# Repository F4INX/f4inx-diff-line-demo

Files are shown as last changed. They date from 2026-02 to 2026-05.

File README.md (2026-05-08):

# Differential pairs experiments

## Introduction and context

A few years ago, following a post about discontinuities of reference planes planes, I stated that differential pairs were popular precisely because they are more tolerant to reference planes discontinuities than single-ended ones, typically due to the following causes:

* Change of reference ground plane in multilayer boards.

* Slot between voltage domains where a power plane is use as a reference plane.

* Slots in the copper pour due to traces inside for 2 layers PCBs using copper fills as ground planes.

Indeed, there is no fundamental physical reason for differential lines alone, without discontinuities, to have better performance than grounded single-ended lines.

After this discussion, I made preliminary experiments to confirm some of my ideas on the subjects, but I did not have time yet to make a more comprehensive test.

After a recent discussion a few weeks ago, I had an idea to perform quick and low cost experiments on the subjects which is presented now.

## Precisions on the statement

After some discussions telling that differential pairs are not totally immune to ground plane issues, some points must be precised:

* Even when differential pairs have a greater resistance to ground plane defects from a functional point of view, the parasitic common mode is likely to cause EMC emissivity issues.

* Some performance degradation is to be expected indeed.

* But the remaining performance is more likely to stay sufficient for functional operation than for single-ended lines.

* The slots are assumed thin, which corresponds to the most common cases.

* For a thin slot, the dominant effect is not the short section with increased impedance, precisely because it is short, but the current redistribution effect explained later.

## Household experiments

### Materials

The only needed material is a low cost HDMI cable. Lowest cost as possible since it will be rather botched. The ticket showing the rather low cost can be seen. The cat is optional, although much welcome.

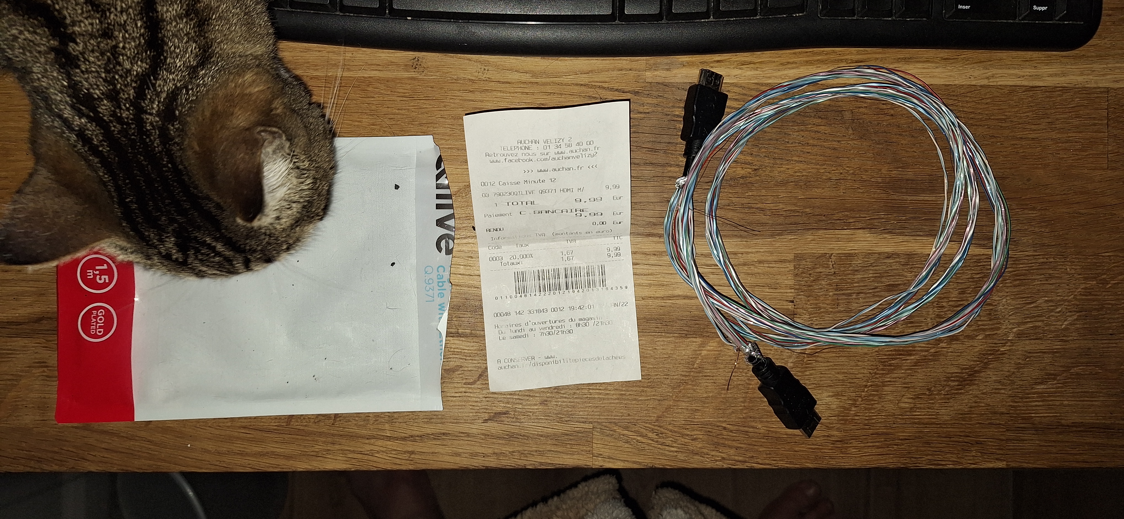
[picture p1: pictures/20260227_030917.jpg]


### Strongly coupled differential pair

First, as a reference, the HDMI pair is measured without its shields, both the outer shield and the inner shields of the pairs.

The small ground wire following the shields was left, even if disconnected. **It can be ignored for understanding of what follows**.

A picture was properly transmitted and displayed using this cable.

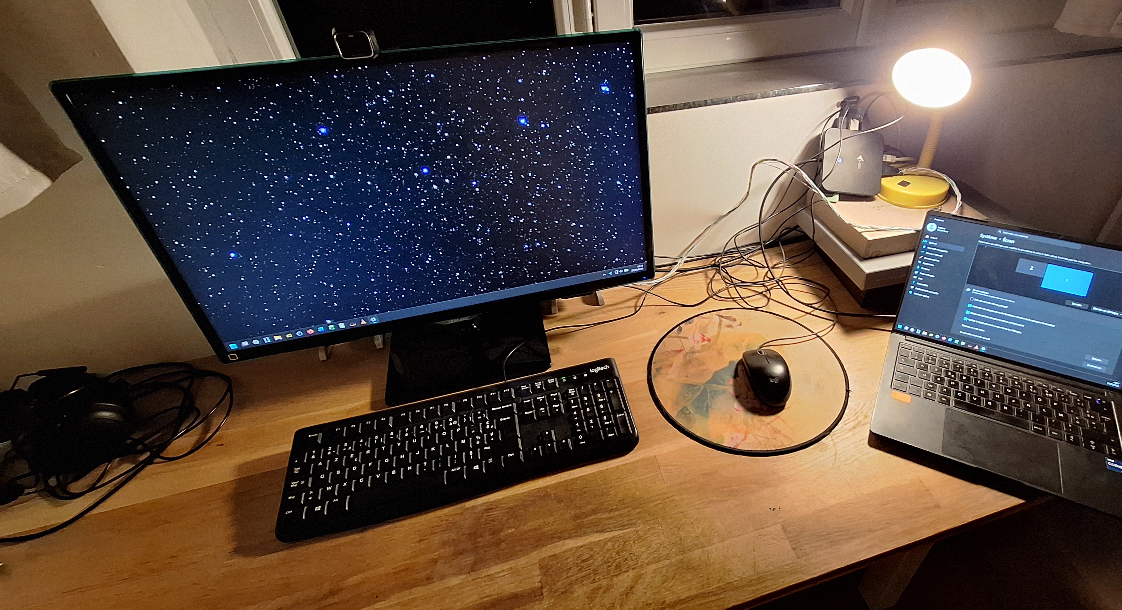
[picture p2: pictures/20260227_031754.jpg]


**Conclusion:** strongly coupled differential pairs don't need a ground "plane" for proper functional operation. ("Plane" in quotes because not plane for a cable, but has the same function.) Shielding is mainly for EMC issues. The question of DC connection to have proper common-mode DC voltage is left aside, but this point is rarely an issue in practice. This case is very common in cables, but in PCBs, the coupling is rarely sufficient to be able to work without a ground plane.

### Very loosely coupled differential pair, with or withound ground

The situation is very different for a loosely differential pair: the characteristic impedance of such lines without a ground plane is too high to ensure a proper operation. The ground plane allows to maintain a correct impedance despite the distance.

As shown below, loosely coupled differential pair without a ground plane have a too high impedance to ensure a proper operation:

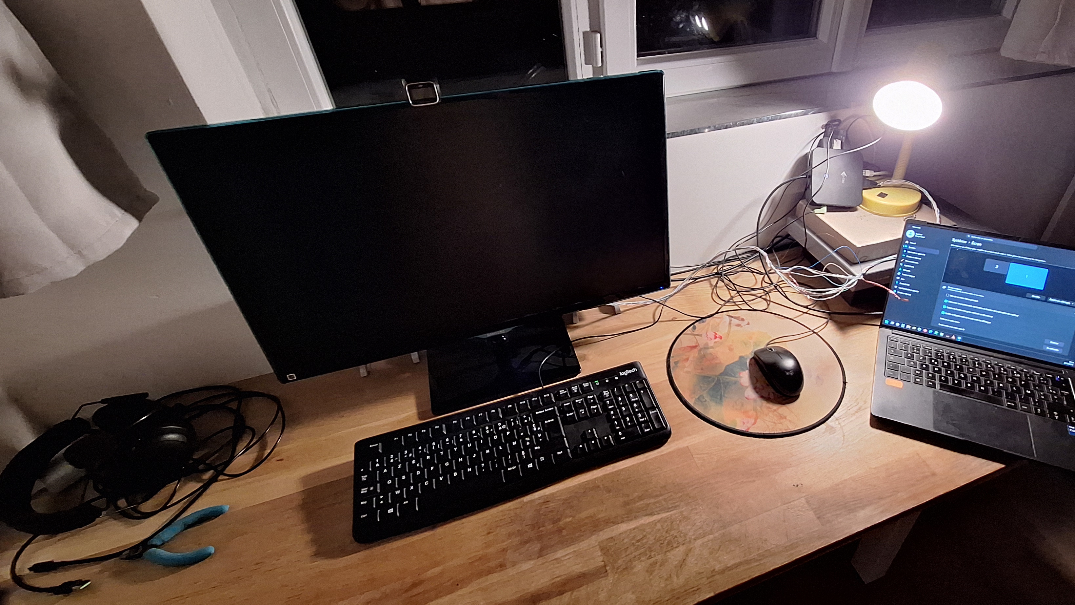
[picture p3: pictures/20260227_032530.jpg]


Adding a ground plane lowers this impedance and allows the differential pair to work again:

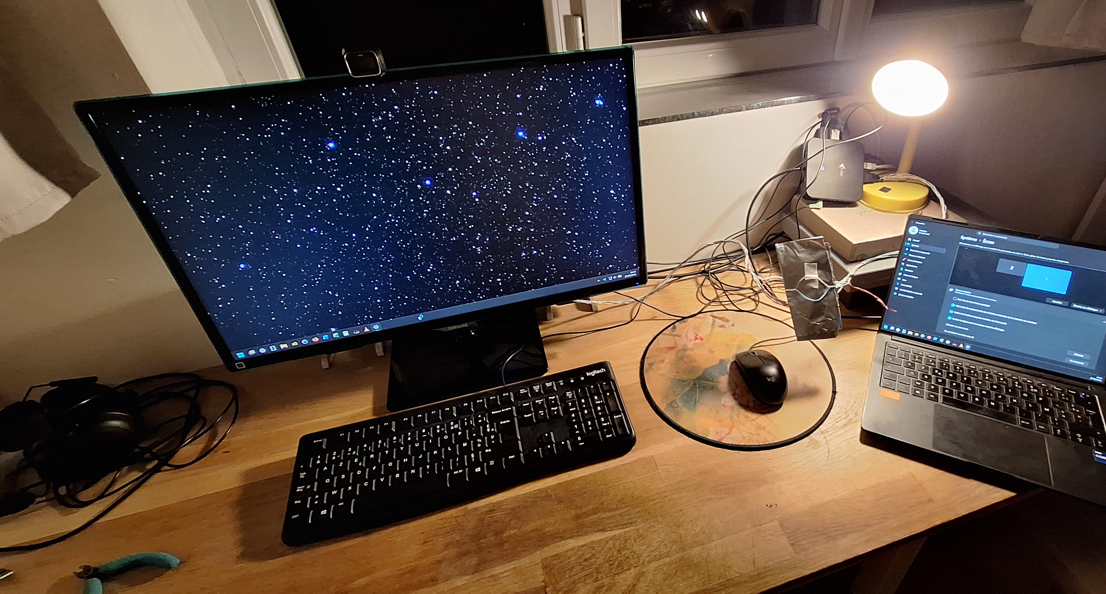
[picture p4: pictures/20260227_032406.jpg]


**However, it is important to note that this ground plane is not (properly) connected to the ground on each sides.** It is only an impedance effect. Indirectly, this test simulates two ground discontinuities before and after the ground plane.

**Conclusion:** when not strongly coupled, coupled differential pairs needs a ground plane to keep the impedance low enough, particularly on a PCB. However, the continuity of this ground does not seem to need to be perfect, as will be detailed later.

### Loosely coupled differential pair crossing a slot

For reasons which will be detailed later, very loosely coupled lines cannot cross a slot without damage.

However, normally loosely coupled lines, as typically seen in a PCB, can cross them without problems.

Pictures below show the displayed transmitted image and the test setup:

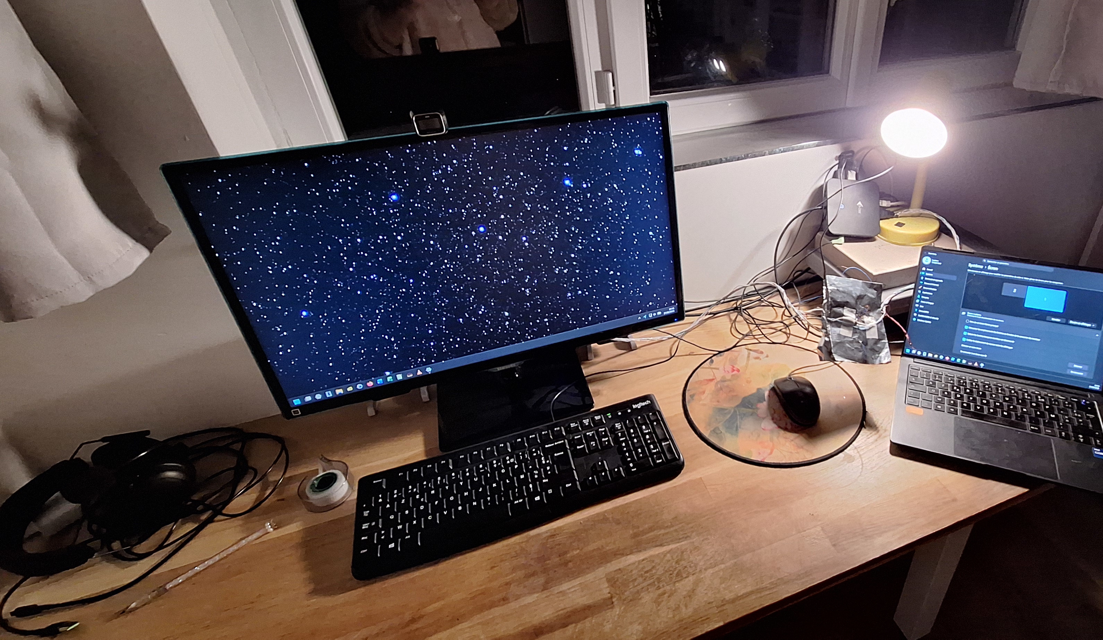
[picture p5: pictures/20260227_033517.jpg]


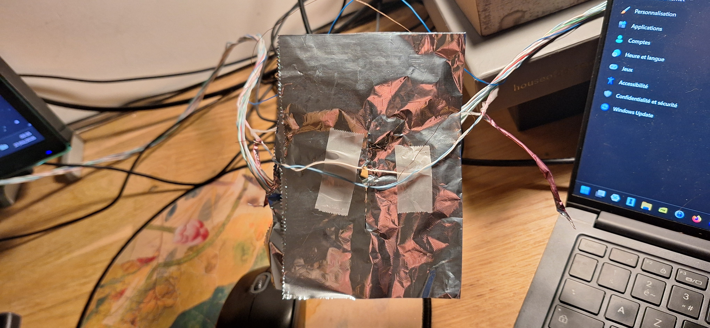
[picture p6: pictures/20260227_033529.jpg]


Unfortunately, the household means used for this setup made the slot very ugly and difficult to see on the picture.

Note that, even with a slot, the ground plane is needed to get the impedance. Sadly, during the lab session, the measurement with this spacing without the ground was forgotten.

The reason why differential pairs behave in this way is that, on the slot, the return current on each line connects with the return current of the other line, as shown in the picture below:

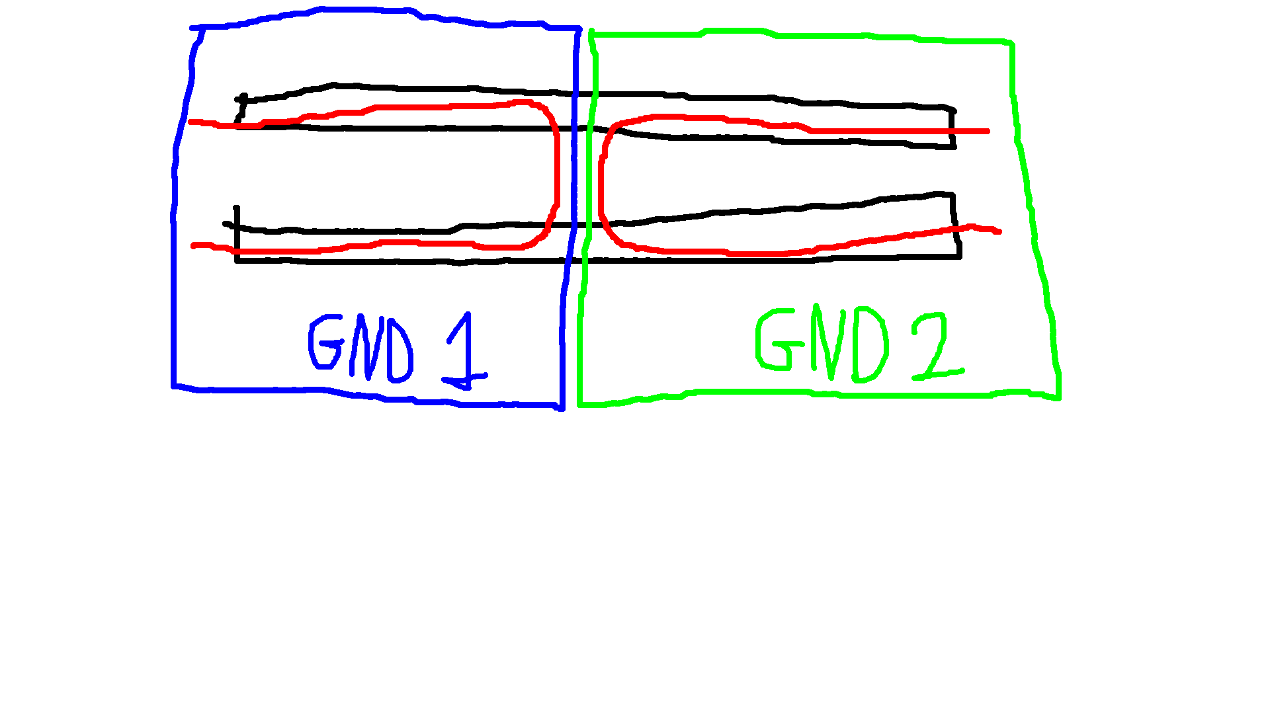
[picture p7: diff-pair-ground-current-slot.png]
diff-pair-ground-current-slot


**Conclusion** due to the balance of the ground return currents, normally loosely coupled differential pairs (i.e. coupling typically used on PCBs) are tolerant to thin slots, even when the ground is needed for impedance.

### Demonstration of the return current balance by breaking it

To test this explanation, a setup where a second perpendicular slot, precisely intended to break the bridging current between the two return currents, was tested. The slots made with household ressources were unfortunately very, very ugly. Still, the results are as expected. Even if this does not make a proof, particularly due to the low quality of the slots, this give confidence for a second version of this setup:

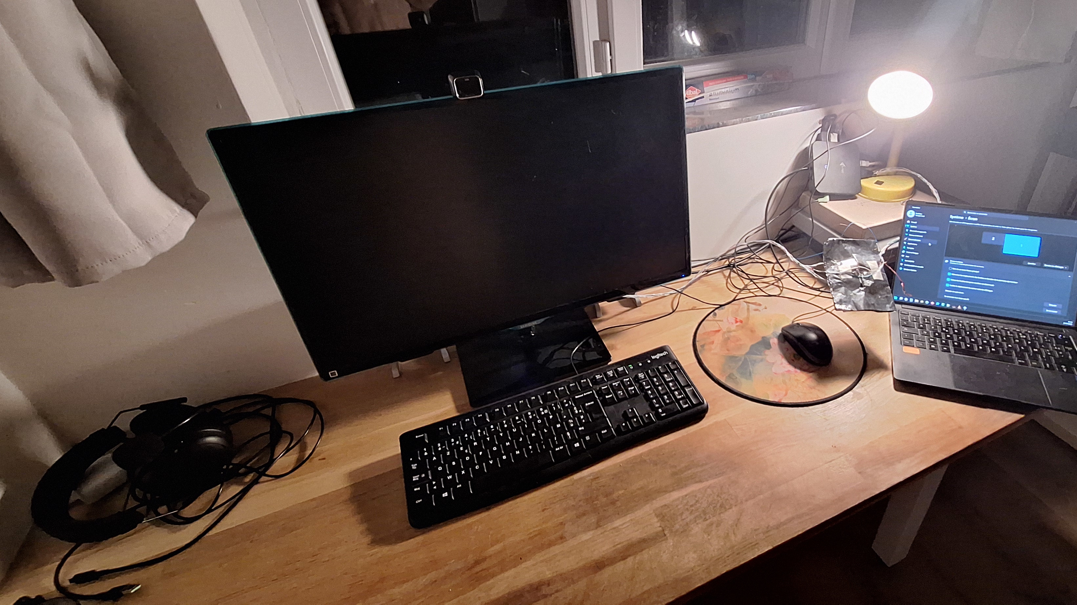
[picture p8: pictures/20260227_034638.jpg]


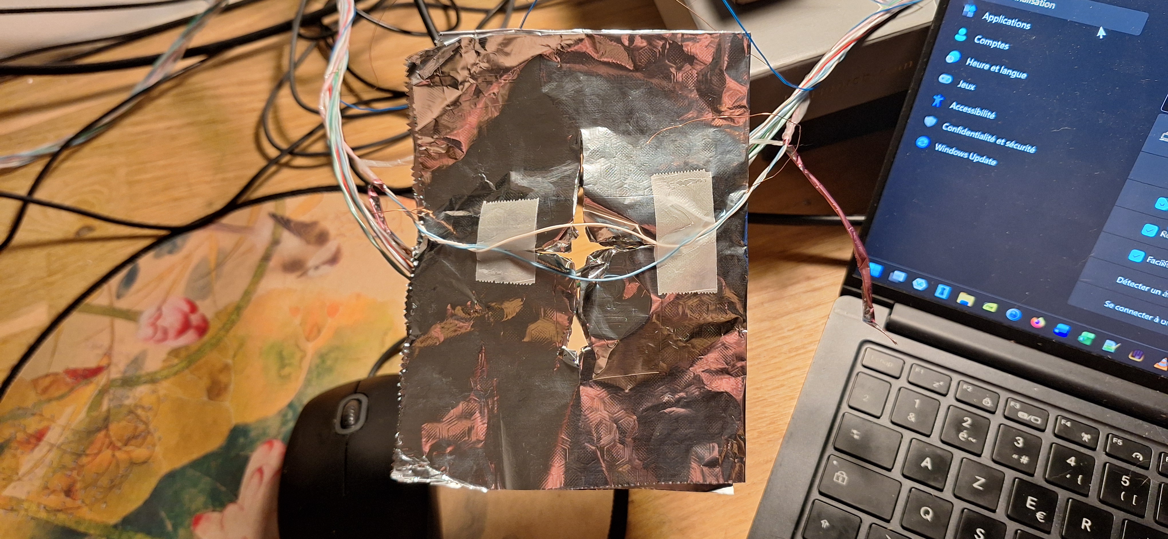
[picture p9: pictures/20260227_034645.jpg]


After this test, I took just in case some measurements, but for the following of the study I will probably make some calculations of EM simulations:

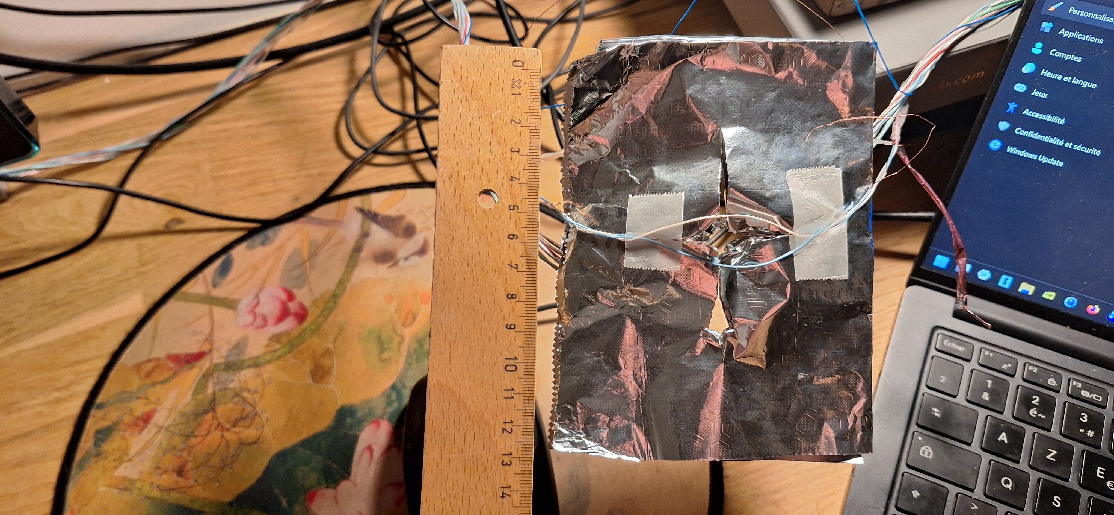
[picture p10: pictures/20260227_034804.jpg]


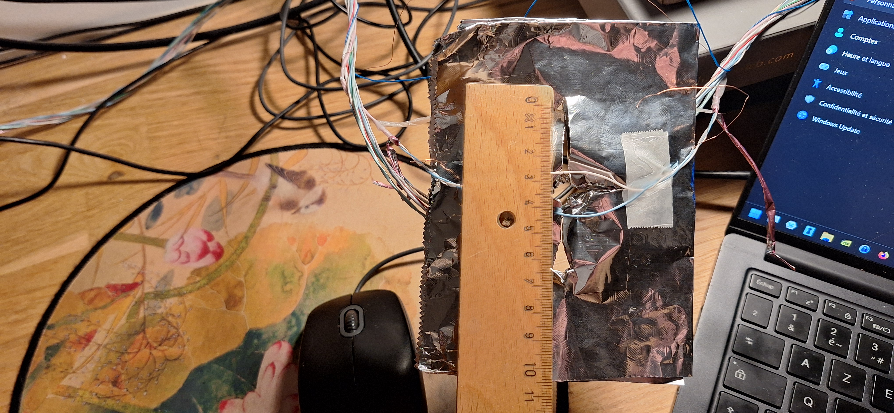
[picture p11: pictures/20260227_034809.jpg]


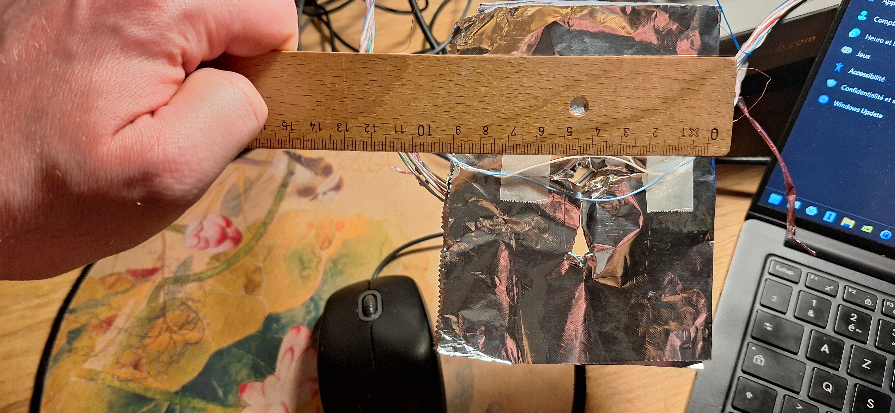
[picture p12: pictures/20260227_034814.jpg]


### Misc comments

Total time spent between first and last pictures: 48 minutes.

## Discussions about the frequencies

The screen used for the tests had a 1920×1080 resolution with a refresh frequency of 60 Hz. Assuming most common parameters for control data and sound channels, according to [https://en.wikipedia.org/wiki/HDMI#Resolution_and_refresh_frequency_limits](https://en.wikipedia.org/wiki/HDMI#Resolution_and_refresh_frequency_limits), a total bitrate of 3.20 Gbit/s is needed, that is 1.07 Gbit/s on each of the 3 data differential pairs, equivalent to a Nyquist frequency of 533 MHz.

Definitely not a very high speed differential pair. For instance, PCI Express uses 2.5 Gbit/s differential pairs since 2003 [https://en.wikipedia.org/wiki/PCI_Express#Comparison_table](https://en.wikipedia.org/wiki/PCI_Express#Comparison_table). Still an interesting experiment, particularly for electronics students.

## Study of a board

### Electromagnetic simulations

Before making an actual board, electromagnetic simulations were performed to determines which configuration would give the best results for a demo.

Given the frequency of the link, a regular slot would need to be very long to have enough effect for the demo. So, an improved slot was used. This would not be needed for very high speed serial links.

The geometry is shown below, along with the calculated eye diagram.

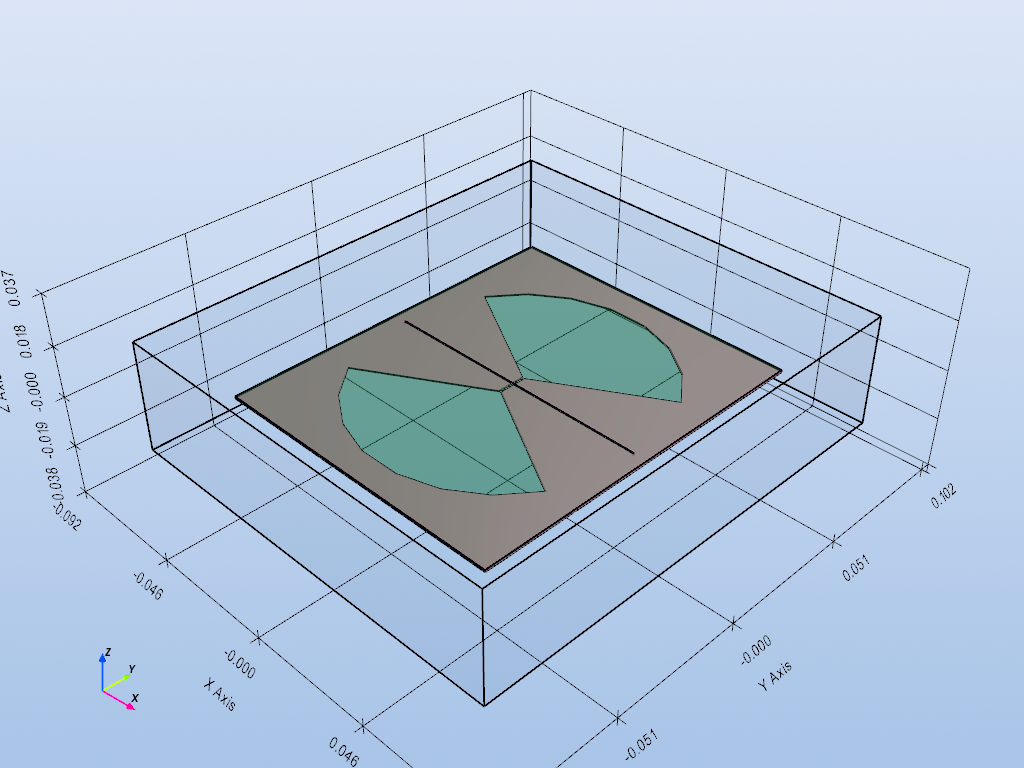
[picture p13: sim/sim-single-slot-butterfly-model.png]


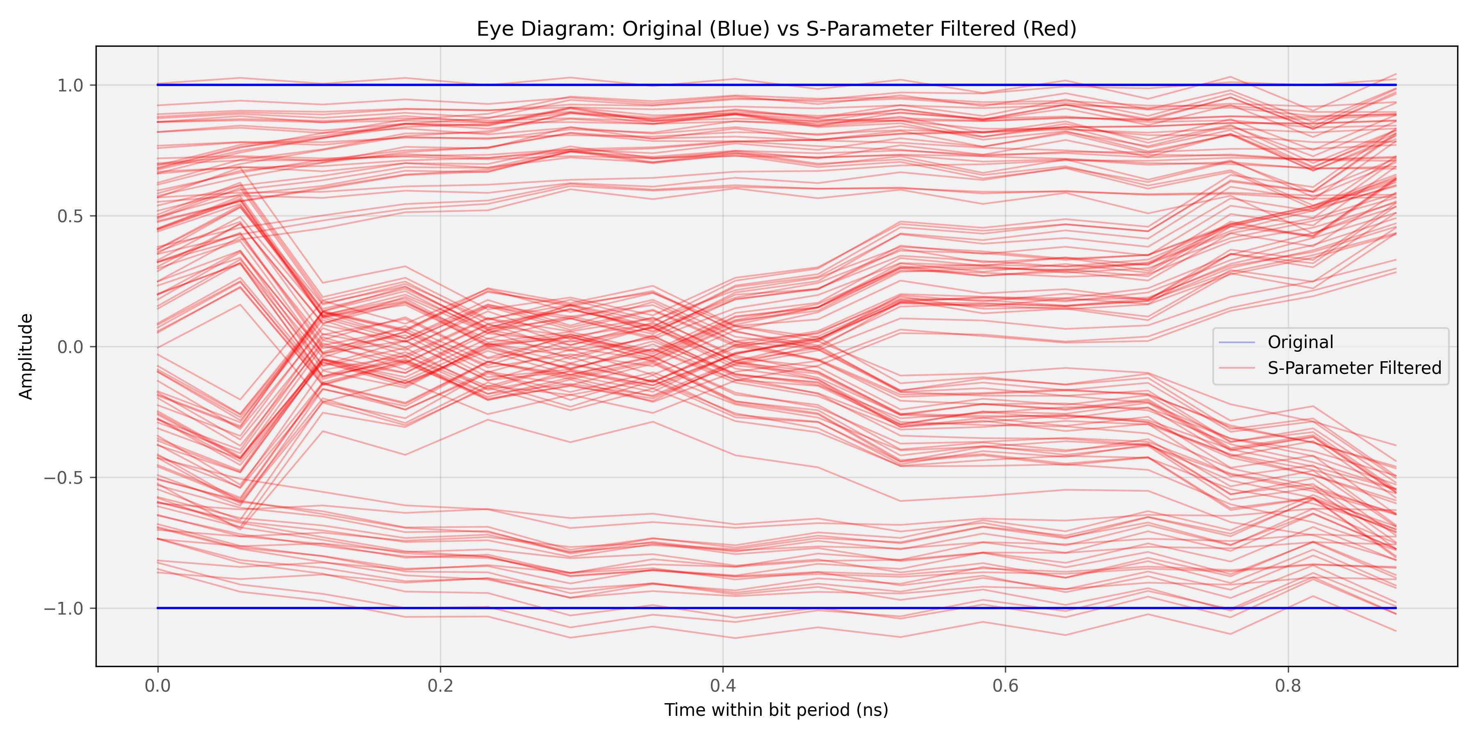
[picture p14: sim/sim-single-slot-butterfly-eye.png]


With a diffrential line, the effect on the eye diagram is spectacular: very clean.

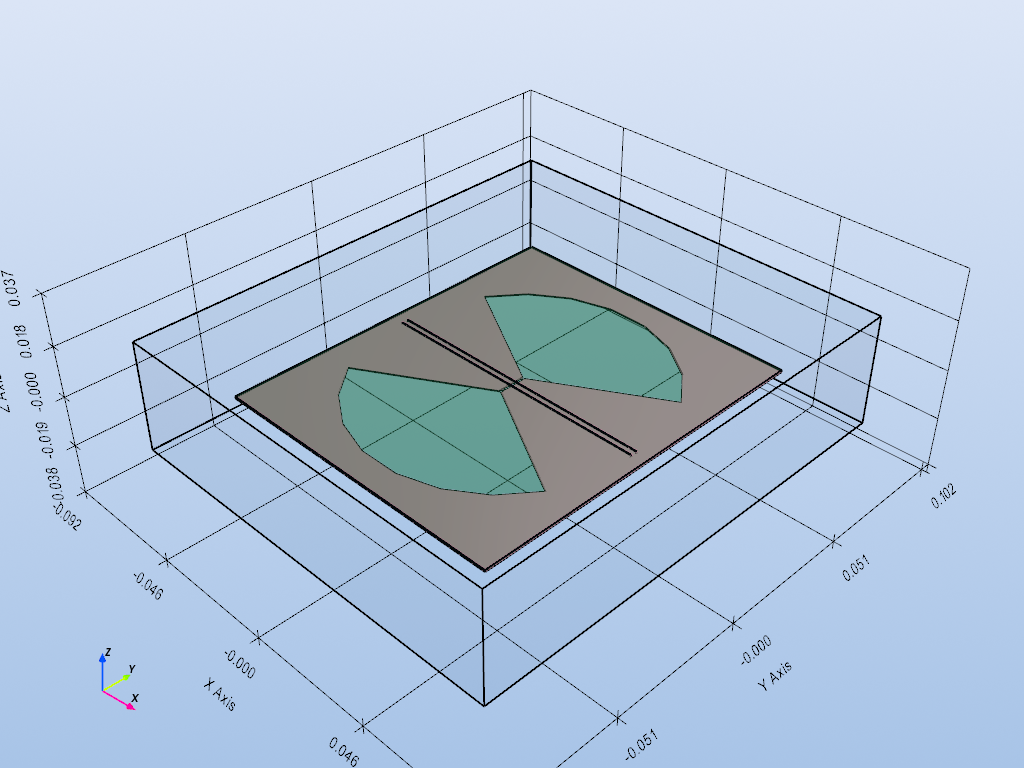
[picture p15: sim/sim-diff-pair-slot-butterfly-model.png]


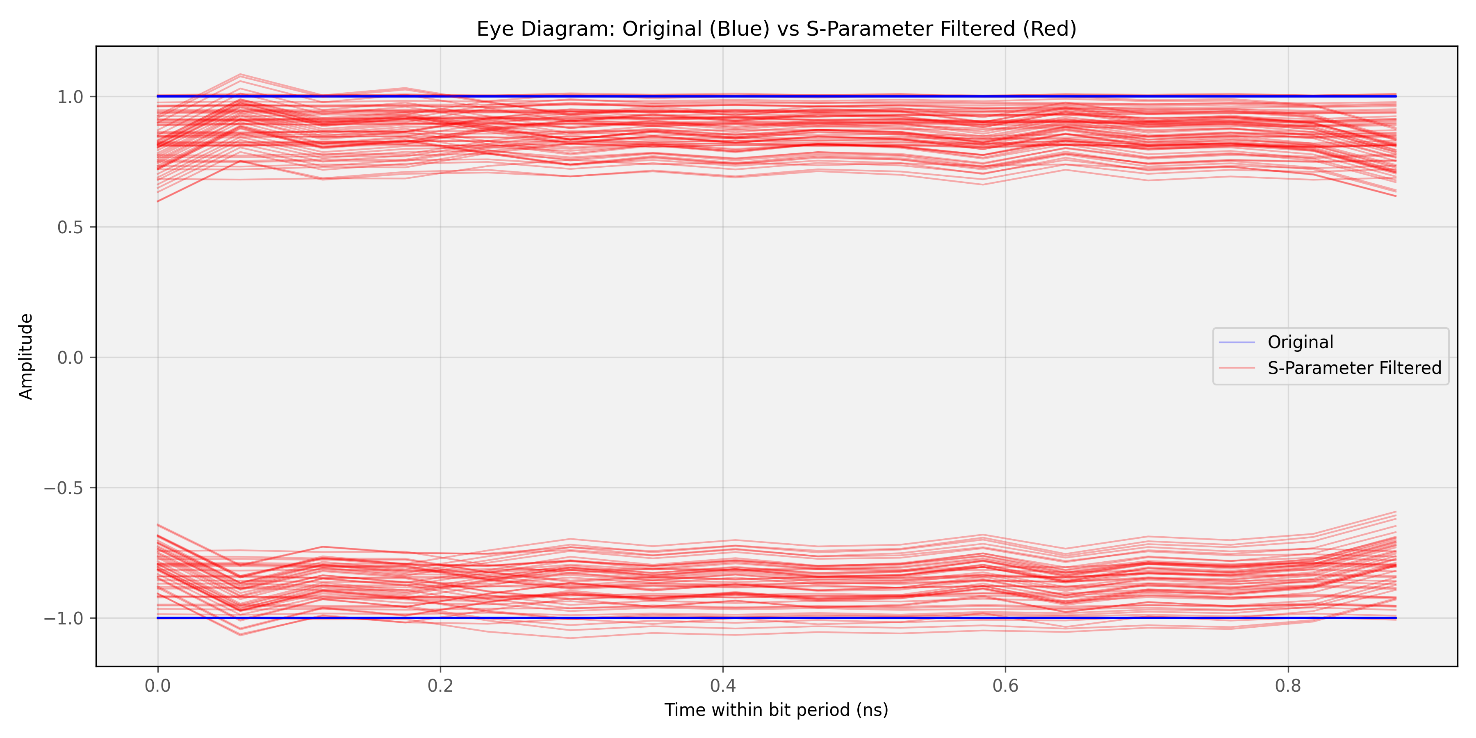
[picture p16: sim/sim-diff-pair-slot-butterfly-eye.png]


The next step is to simulate the 2 slots:

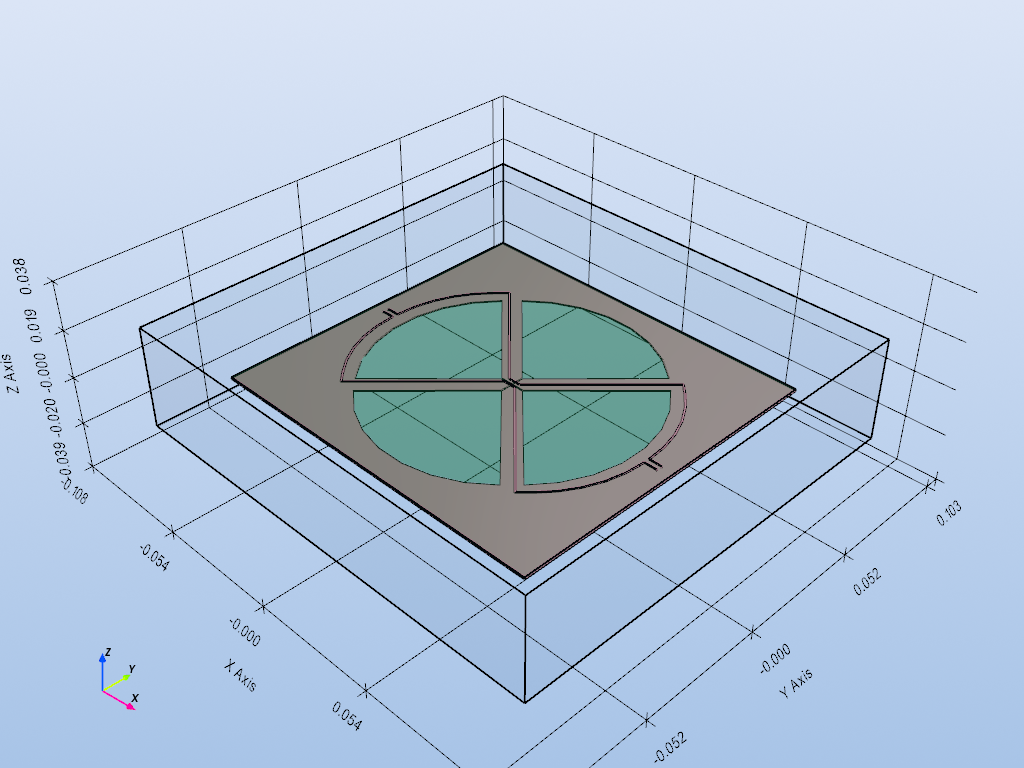
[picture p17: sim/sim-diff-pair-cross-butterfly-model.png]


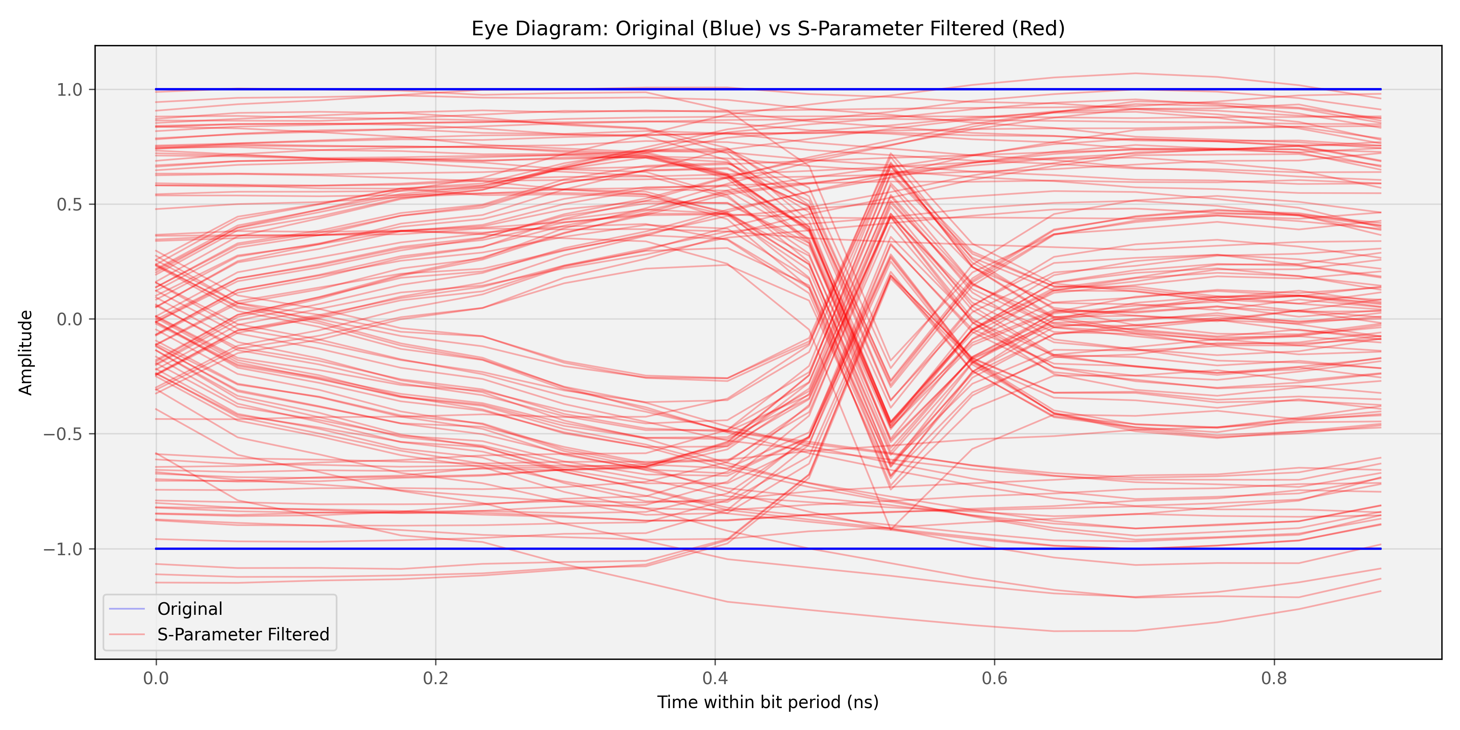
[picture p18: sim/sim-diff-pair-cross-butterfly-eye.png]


A perfectly awful eye diagram.

Simulation with only the vertical slot has a perfectly clean eye diagram, demonstrating the return current effect:

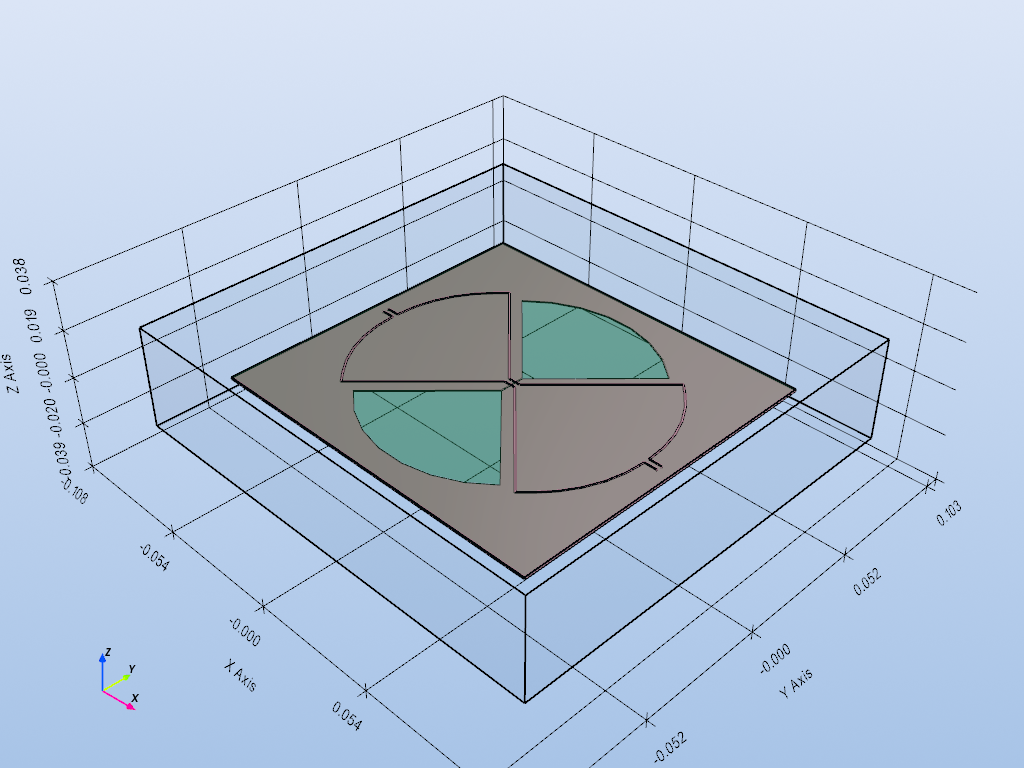
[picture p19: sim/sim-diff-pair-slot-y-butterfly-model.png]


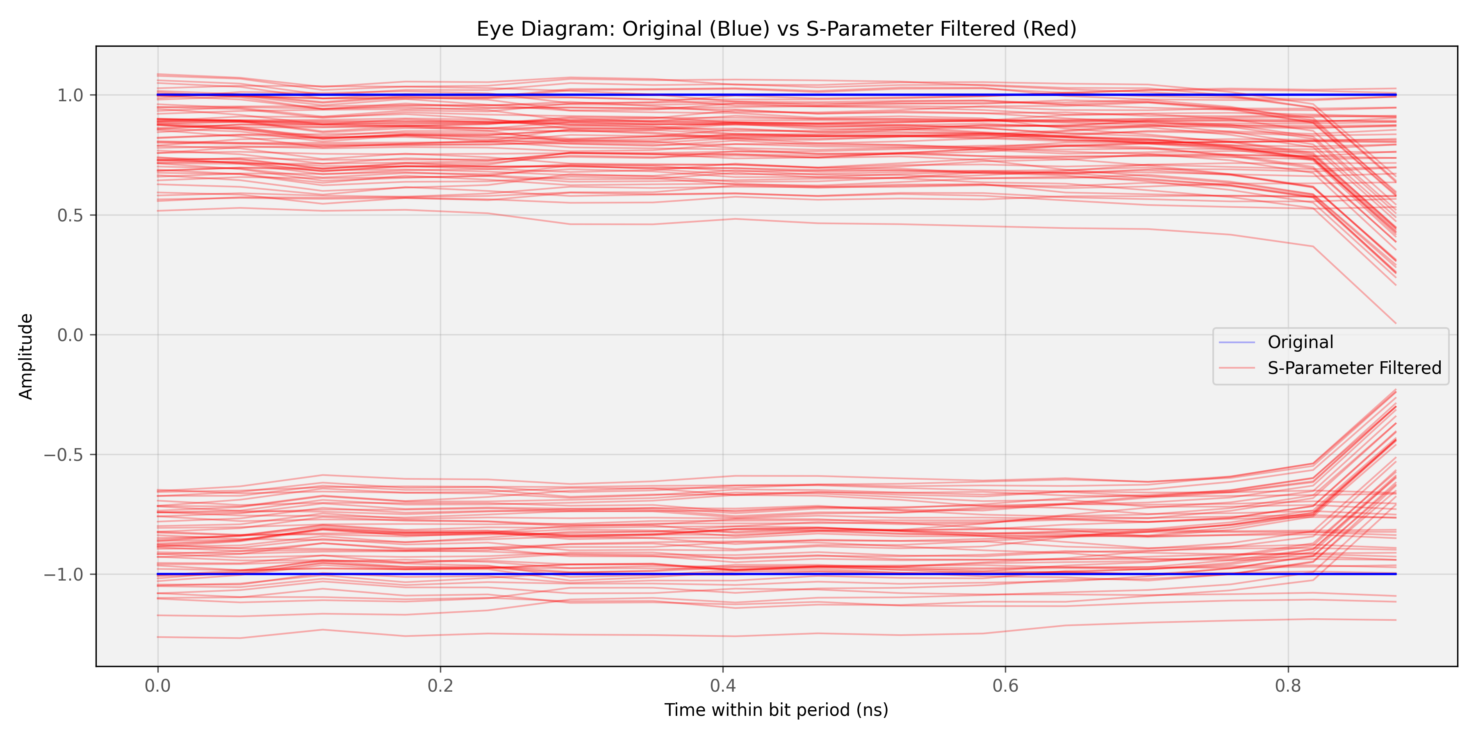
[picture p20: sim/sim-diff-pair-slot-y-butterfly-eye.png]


For the principle, a reference simulation without slots has also been performed. Eye diagram is also very clean, although not perfect due to the losses due to the length of lines:

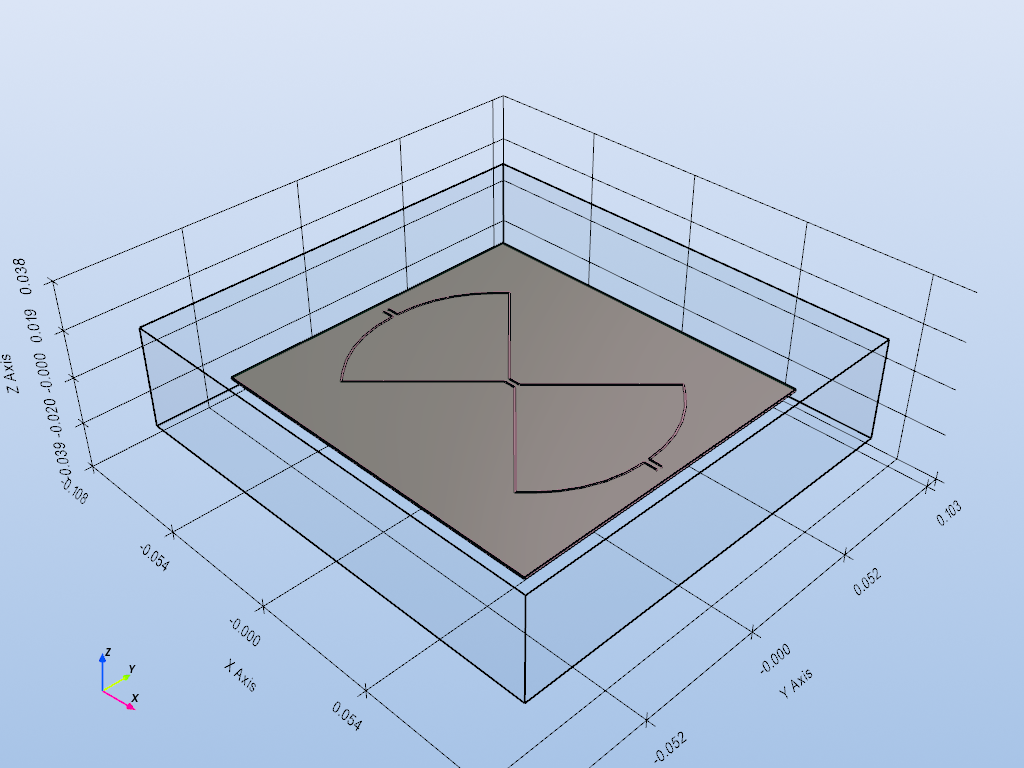
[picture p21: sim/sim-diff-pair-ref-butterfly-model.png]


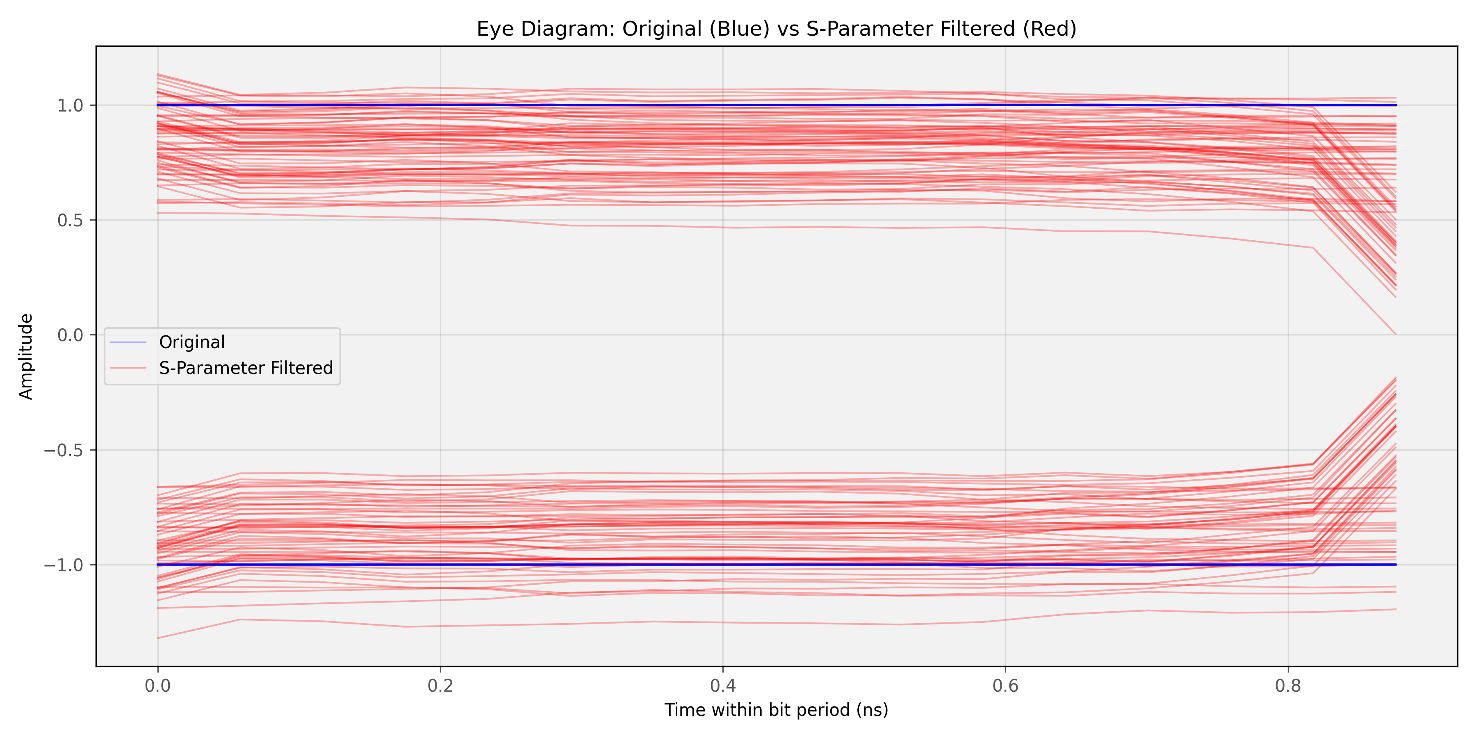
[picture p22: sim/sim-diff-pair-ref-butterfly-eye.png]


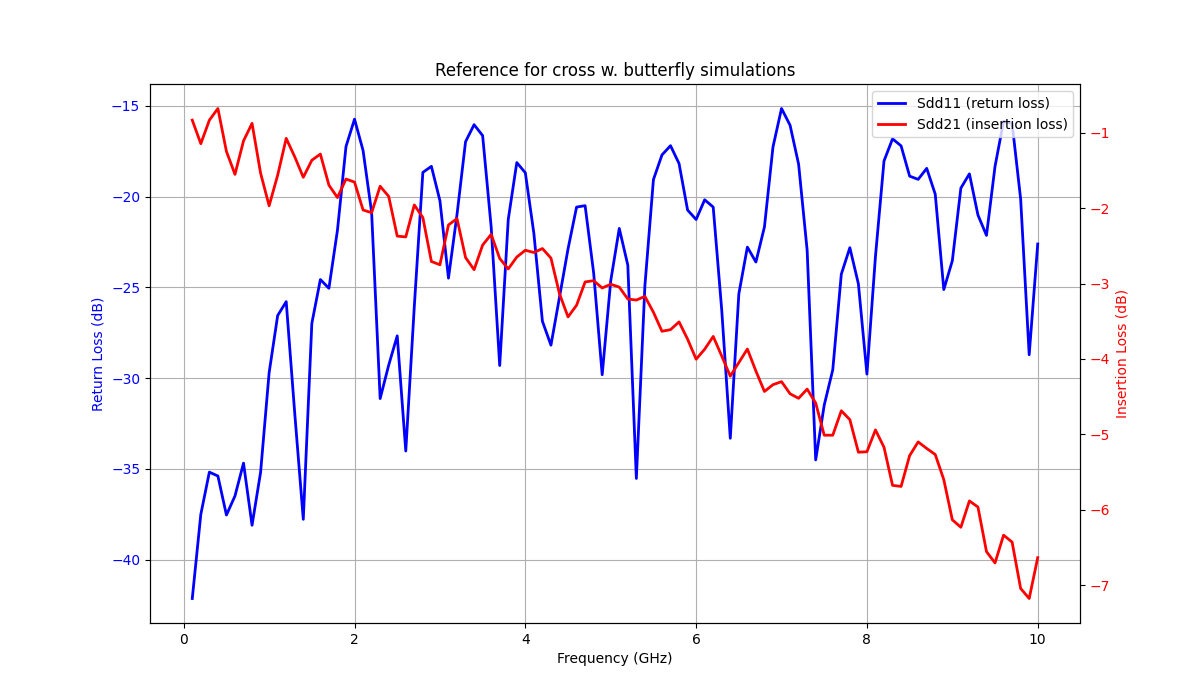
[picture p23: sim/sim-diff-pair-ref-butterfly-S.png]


These simulations confirm the underlying principle and provide guidelines for the test board.

## Board

Many thanks to Petr Dvořák for advice on the best way to draw the slot on the PCB.

Currently, a first draft was routed, and a price for manufacturing through JLCPCB was obtained:

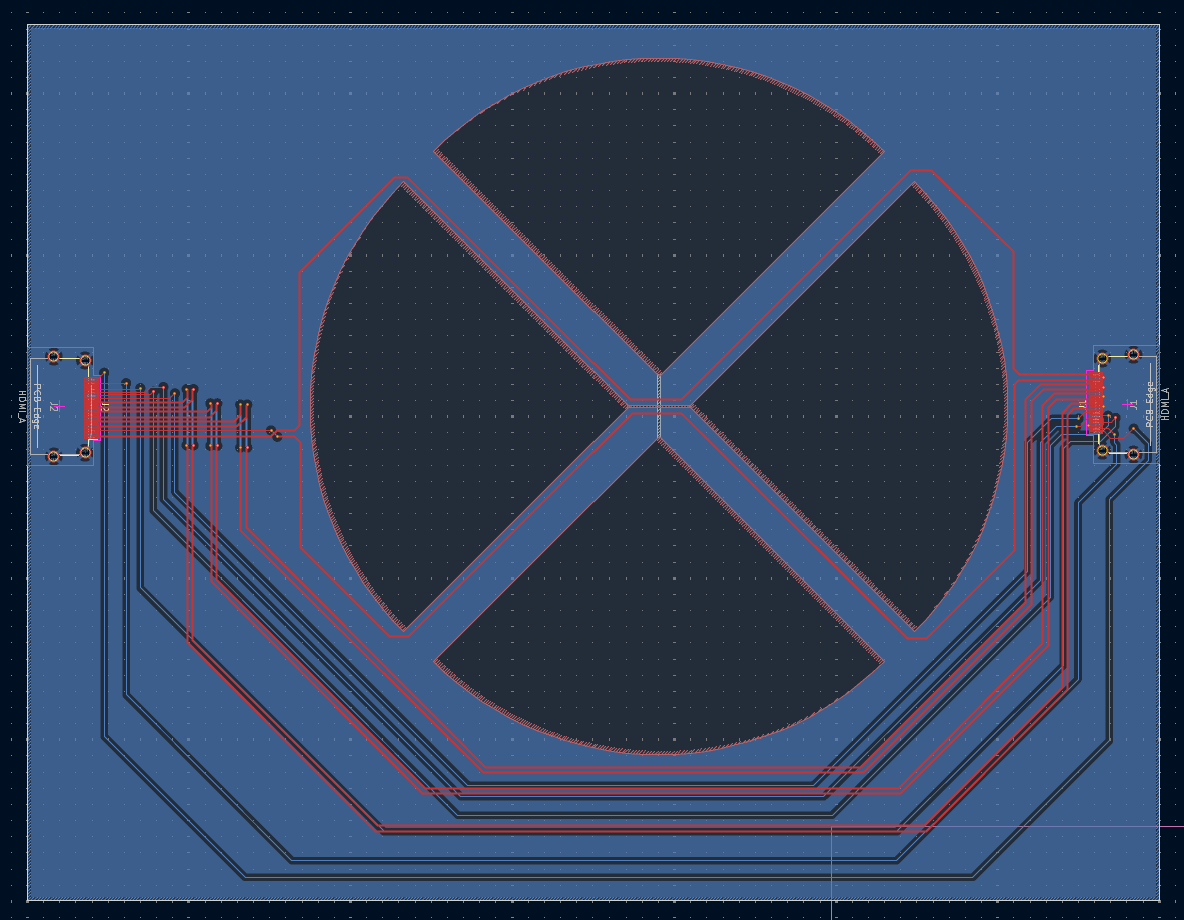
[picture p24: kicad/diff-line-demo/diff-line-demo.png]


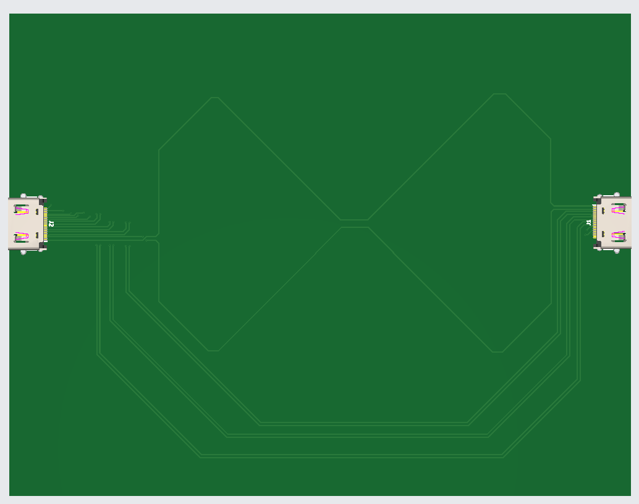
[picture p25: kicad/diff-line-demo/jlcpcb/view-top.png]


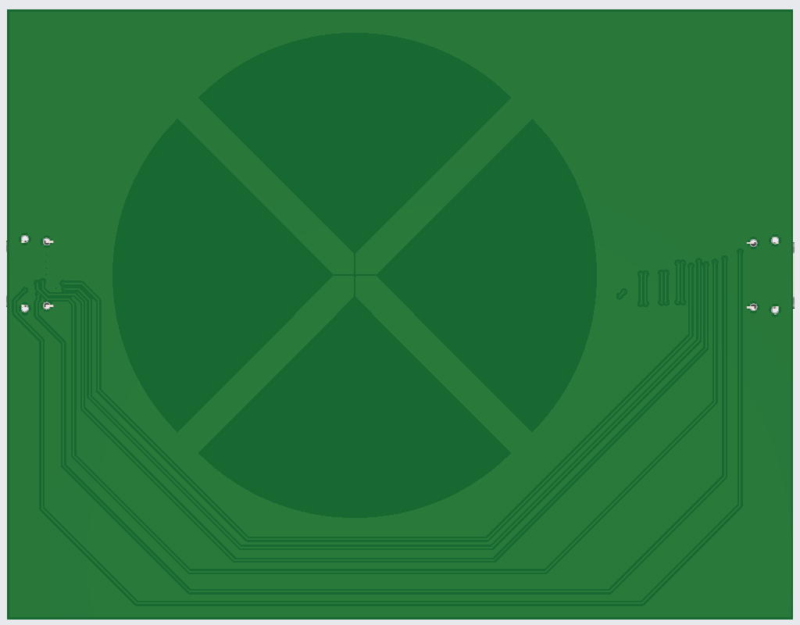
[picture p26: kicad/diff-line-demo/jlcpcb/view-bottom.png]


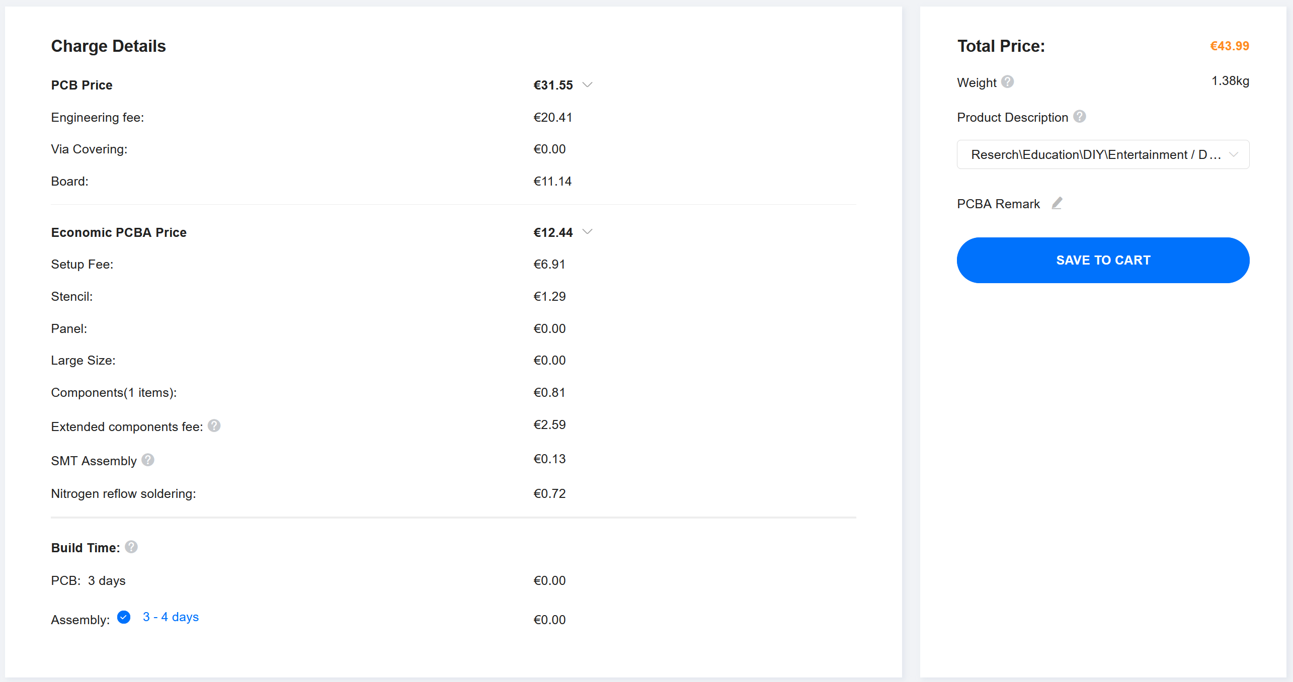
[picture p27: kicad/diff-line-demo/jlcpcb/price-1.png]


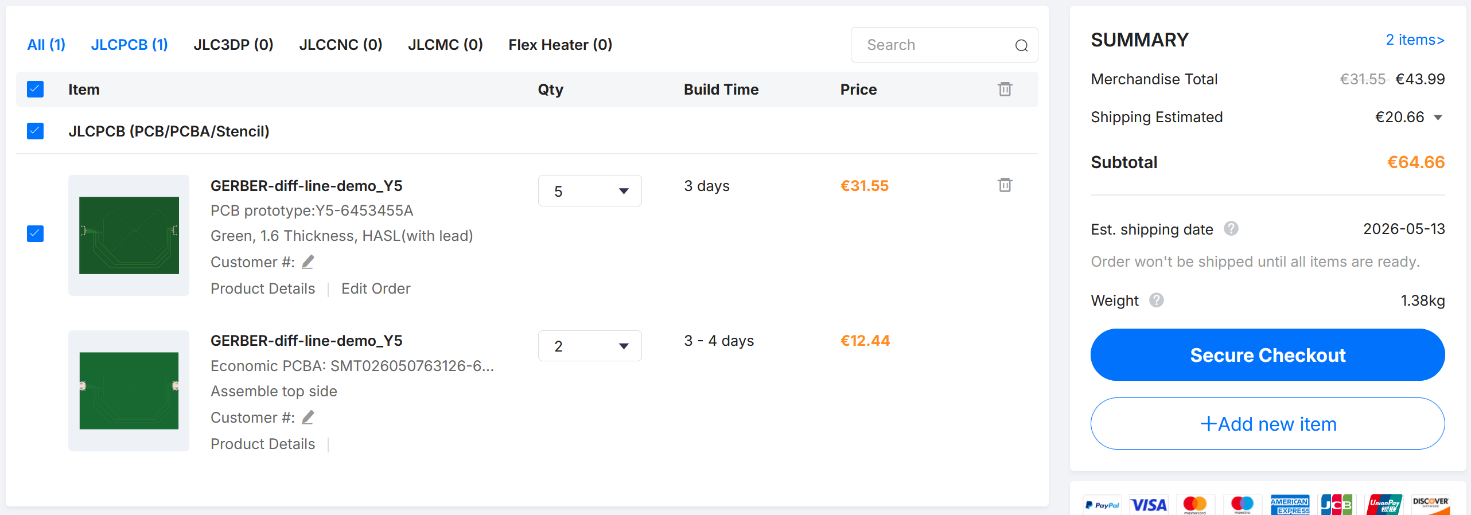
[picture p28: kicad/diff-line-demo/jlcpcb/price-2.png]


According to [https://www.reddit.com/r/JLCPCBLab/comments/1m047l9/what_is_the_reason_for_getting_charged_for_the/](https://www.reddit.com/r/JLCPCBLab/comments/1m047l9/what_is_the_reason_for_getting_charged_for_the/), this fee is charged when any dimension of the board is higher than 100 mm.

Ideally, several cases should be tested in a single board, at least the cross and the slot case. A pricing attempt was made to see if it would be feasible at a reasonable price. For this, the board was simply enlarged and sent to JLCPCB:

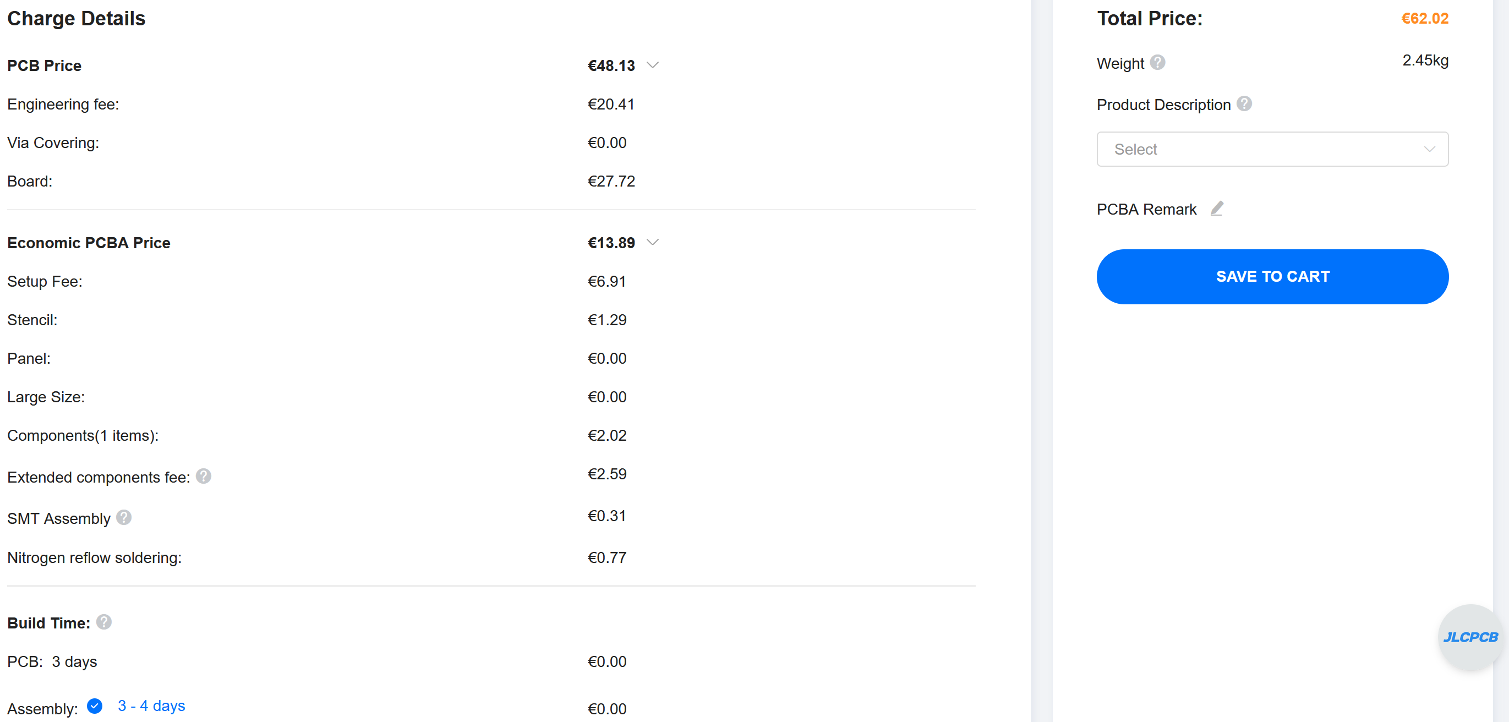
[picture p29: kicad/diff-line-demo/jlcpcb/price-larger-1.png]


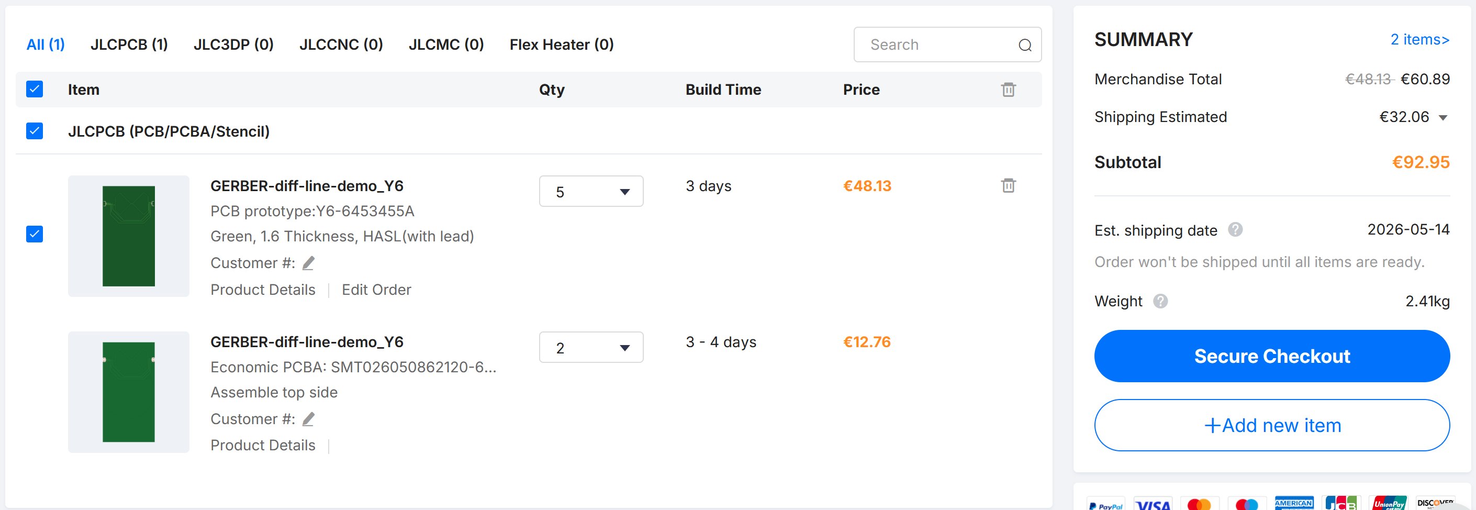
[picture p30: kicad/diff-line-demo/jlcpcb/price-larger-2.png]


The total price is rather high for this test. Other solutions should be found.

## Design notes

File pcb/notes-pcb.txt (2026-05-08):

JLCPCB, 2 layers, FR4, 0.8 mm, 1 oz (35 µm) copper.
Material info: https://jlcpcb.com/help/article/UL-Certification, https://drive.google.com/file/d/12ExhD1_hhs4CnjImo46i_ZlCUNnHff2M/view
Typical value: 4.6 mm.

Calculations with TXLine: 1.44 mm wide single-ended, 1.14 mm for loosely coupled diff pairs (gap 1 mm).
Should be OK, but width is not convenient.

HDMI connector: https://jlcpcb.com/partdetail/149706-HDMI_00119PCBTP/C138388
  0.3 mm pins, difficult to match traces.

Switch to 4 layers.

JLCPCB, 4 layers, default stackup, 7628, 0.21040 mm, 1 oz (35 µm) copper.
https://jlcpcb.com/impedance
4.4 dielectric constant, frequency not specified, neither loss tangent.

Calculations with TXLine: ok, use 0.36 mm for both single-ended and diff pairs with 2 mm gap (loose coupling).

Dimensions ok for connector.

https://jlcpcb.com/parts/2nd/Connectors/HDMI_Connectors_3260
https://jlcpcb.com/partdetail/149706-HDMI_00119PCBTP/C138388

After begin of layout, use https://jlcpcb.com/partdetail/AmphenolICC-10029449111RLF/C427307

Some lines need tighter coupling: 0.36 mm almost ok with 0.5 mm gap.

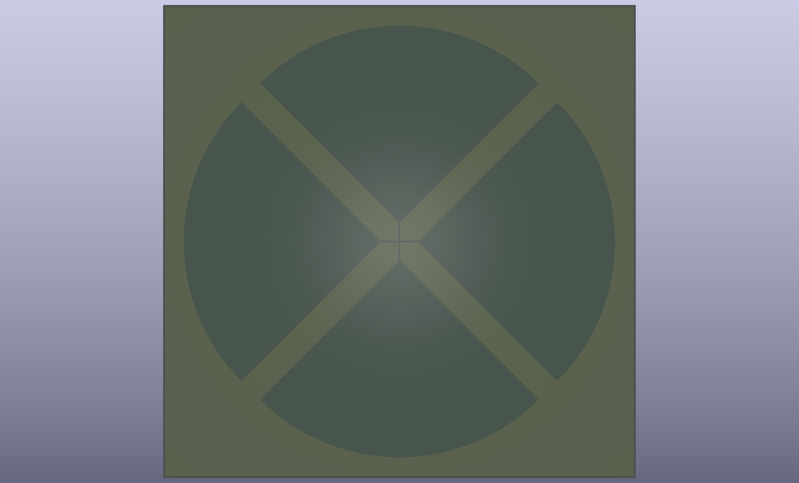
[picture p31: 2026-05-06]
pictures/20260506_213500_slot.png

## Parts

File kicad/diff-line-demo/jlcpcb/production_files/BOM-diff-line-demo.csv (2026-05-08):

Comment | Designator | Footprint | LCSC | Quantity
HDMI_A | J1,J2 | HDMI_A_Amphenol_10029449-x01xLF_Horizontal | C138388 | 2

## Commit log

2026-03-30 Add connectors from JLCPCB.
2026-04-27 EM simulation and eye diagram of a test slot with single-ended and diff pair.
    [sim-diff-pair-slot-butterfly-S.csv, sim-single-slot-butterfly-S.csv]
2026-04-27 Cross simulation.
    [sim-diff-pair-cross-butterfly-S.csv]
2026-04-27 Reference simulation.
    [sim-diff-pair-ref-butterfly-S.csv]
2026-04-27 Transverse slot simulation.
    [sim-diff-pair-slot-y-butterfly-S.csv]
2026-05-06 Init Kicad project.
    [diff-line-demo.kicad_pcb, diff-line-demo.kicad_sch]
2026-05-06 Butterfly slot using Inkscape + DXF import (thanks to Petr Dvořák for the tip).
    [diff-line-demo.kicad_pcb]
2026-05-06 Fix layers of the ground plane and slots.
    [diff-line-demo.kicad_pcb]
2026-05-06 Pictures of first PCB slot draft in README.md
2026-05-07 HDMI connectors selection, begin of PCB.
    [diff-line-demo.kicad_pcb, diff-line-demo.kicad_sch]
2026-05-07 Route all signals.
    [diff-line-demo.kicad_pcb, diff-line-demo.kicad_sch]
2026-05-07 Rename test-slot.svg into slot.svg.
2026-05-07 JLCPCB price for first version.
    [BOM-diff-line-demo.csv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]
2026-05-08 Pricing of larger board.
    [diff-line-demo-CuBottom.gbr, diff-line-demo-CuIn1.gbr, diff-line-demo-CuIn2.gbr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]
2026-05-08 Revert "Pricing of larger board."
    This reverts commit 5b3cc41474cecd1aedfbfebfedbf0e034cb78ffa.
    [diff-line-demo-CuBottom.gbr, diff-line-demo-CuIn1.gbr, diff-line-demo-CuIn2.gbr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]
2026-05-08 Comments about larger board.
